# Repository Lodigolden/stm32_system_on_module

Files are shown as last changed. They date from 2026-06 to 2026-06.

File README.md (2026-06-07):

# STM32H7 System-on-Module
## Overview
This STM32H7 system-on-module is everything needed to get the MCU up and running. Simply place a footprint for the board-to-board connectors on your motherboard, and use whatever pins your project needs!

## Hardware
The system-on-module is a powerful compute source with everything you need for intensive computation. Peripherals include:
- STM32H743ZGT6 32Bit MCU
- AS4C8M16SA-7TCN 128MBit SDRAM
- AT25FF161A-SSHN-T 16MBit QSPI Flash
- CP2102N-A02-GQFN20R USB-to-UART Bridge

The system on module has a point-of-load regulator (TPSM861253RDXR) to ensure stable, efficient power delivery to on-board peripherals.

## Firmware
Included in this repository is a device tree file and other necessary files for building a zephyr image. The **fw/** README.md file gives instructions for building on a Linux system.

> TODO: Write instructions for Windows use.

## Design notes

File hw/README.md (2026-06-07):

# Overview
The **pinout/** directory includes an STMCubeIDE file used to deetermine pinouts for the on-board components. If the end user doesn't wish to use Zephyr and would rather use STMCubeIDE, they can feel free to start with that folder.

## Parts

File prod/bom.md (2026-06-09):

# Bill of Materials

| Part Number | QNTY |
|:---|----:|
| 10118192-0002LF | 1 |
| AS4C8M16SA-7TCN | 1 |
| AT25FF161A-SSHN-T | 1 |
| CL05B104KP5VPNC | 28 |
| CL10A475KO8NNNC | 3 |
| CL31A226MOCLNNC | 1 |
| CL31B106KAHNFNE | 1 |
| CP2102N-A02-GQFN20R | 1 |
| DF40C-50DP-0.4V(51) | 2 |
| ERJ-2RKF3300X | 1 |
| GRM155Z71A105KE01D | 2 |
| KC2016Z8.00000C15XXK | 1 |
| LO Q976-PS-25-0-20-R18 | 1 |
| MSS1P4-M3/89A | 2 |
| RC0402FR-071KL | 1 |
| RC0402FR-0722K1L | 1 |
| RC0402FR-0747K5L | 1 |
| RC0402FR-074K99L | 1 |
| RC0402JR-0733RL | 44 |
| RMCF0402FT10K0 | 2 |
| SMAJ7.0CA | 1 |
| STM32H743ZGT6 | 1 |
| TPD1E10B06DYAR | 2 |
| TPSM861253RDXR | 1 |

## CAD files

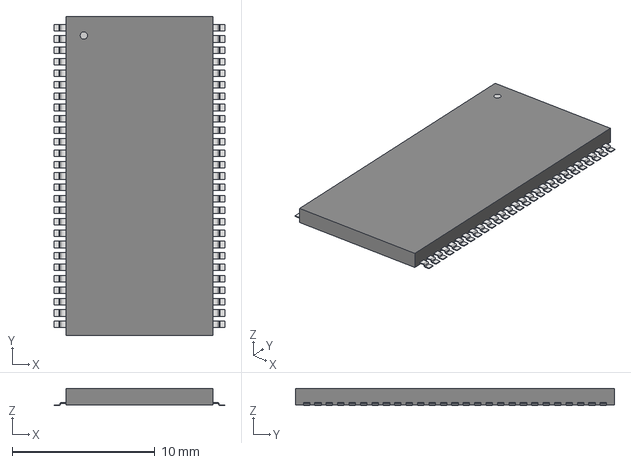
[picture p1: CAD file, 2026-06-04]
hw/components/as4c8m16sa_7tcn/TSOP-54_11P96X22P35_ALL.step
12.0 x 22.4 x 1.20 mm

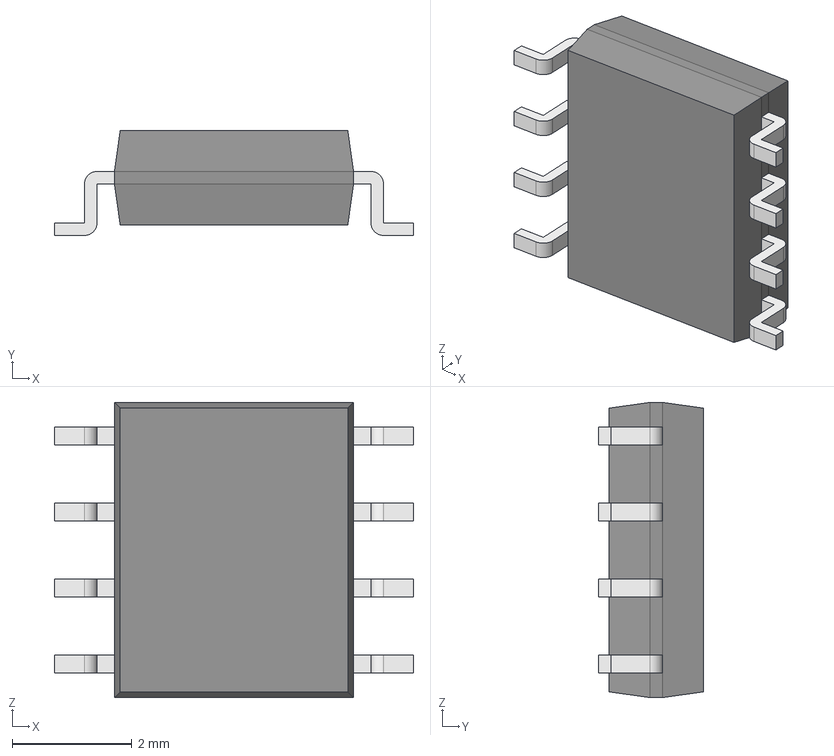
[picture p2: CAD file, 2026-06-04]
hw/components/at25ff161a/AT25FF161A-SSHN-T.step
5.99 x 1.75 x 4.92 mm
Body001 (Mirror #1) x 4
XY-plane x 12
X-axis x 12

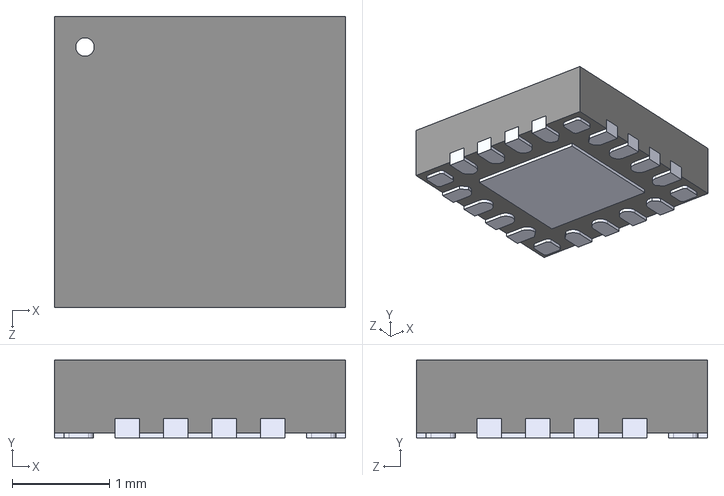
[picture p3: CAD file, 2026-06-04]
hw/components/cp2102n-a02-gqfn20r/CP2102N-A02-GQFN20R.step
3.00 x 0.8 x 3.00 mm

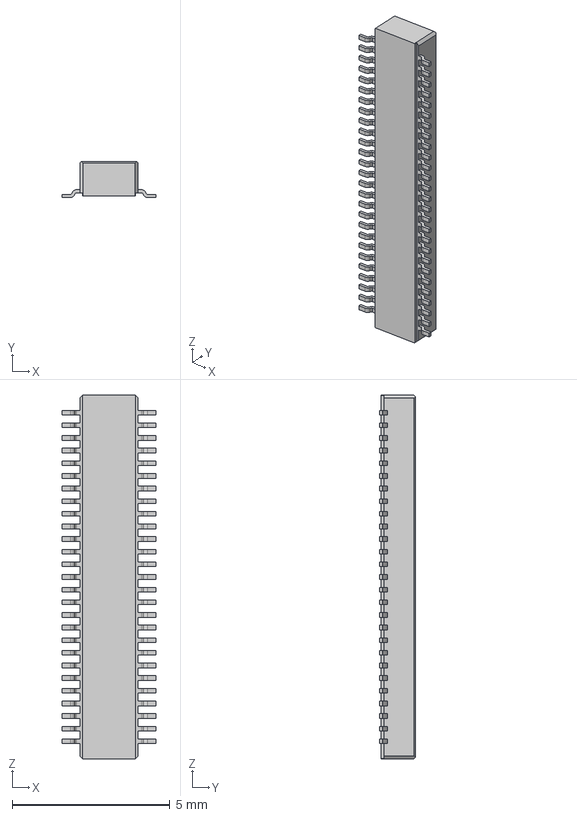
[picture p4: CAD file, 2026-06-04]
hw/components/dc40c_50dp_0.4v_51/DF40C-50DP-0.4V_51_.step
2.97 x 1.14 x 11.5 mm

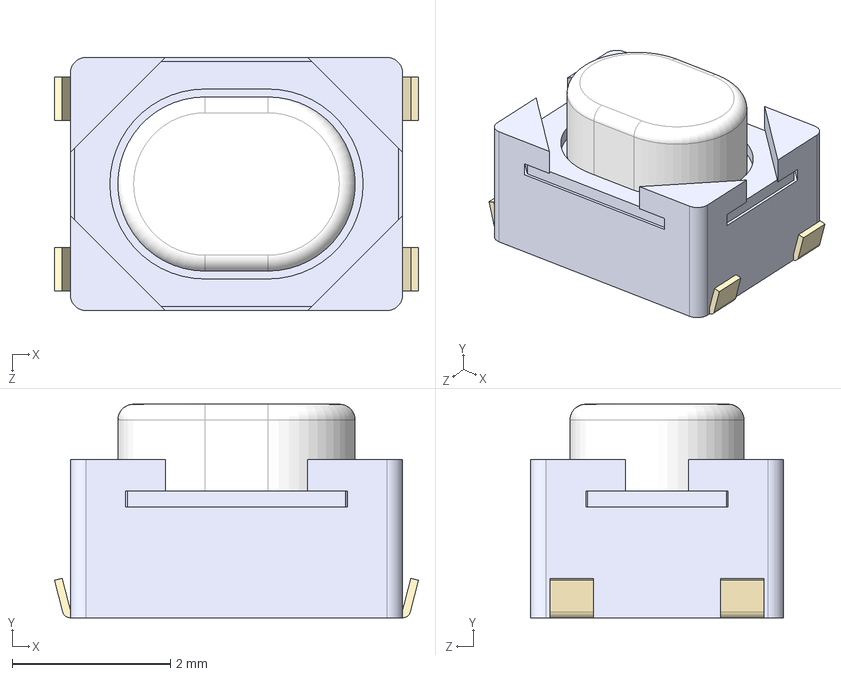
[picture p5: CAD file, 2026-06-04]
hw/components/PTS810SJK250SMTR_LFS/PTS810SJK250SMTRLFS--3DModel-STEP-56544.STEP
4.60 x 2.70 x 3.20 mm

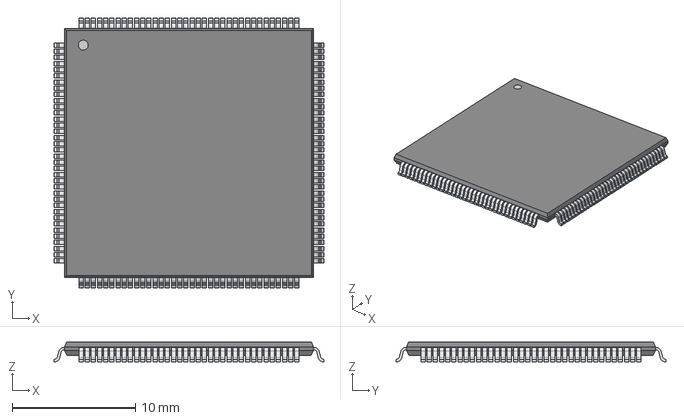
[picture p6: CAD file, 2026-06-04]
hw/components/stm32h743zgt6/LQFP144-20x20mm.step
21.9 x 21.9 x 1.60 mm

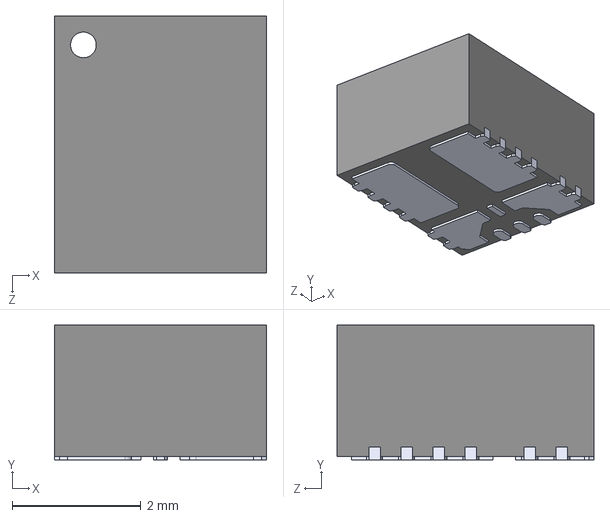
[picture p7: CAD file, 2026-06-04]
hw/components/tpsm861253/TPSM861253RDXR.step
3.30 x 2.10 x 4.00 mm

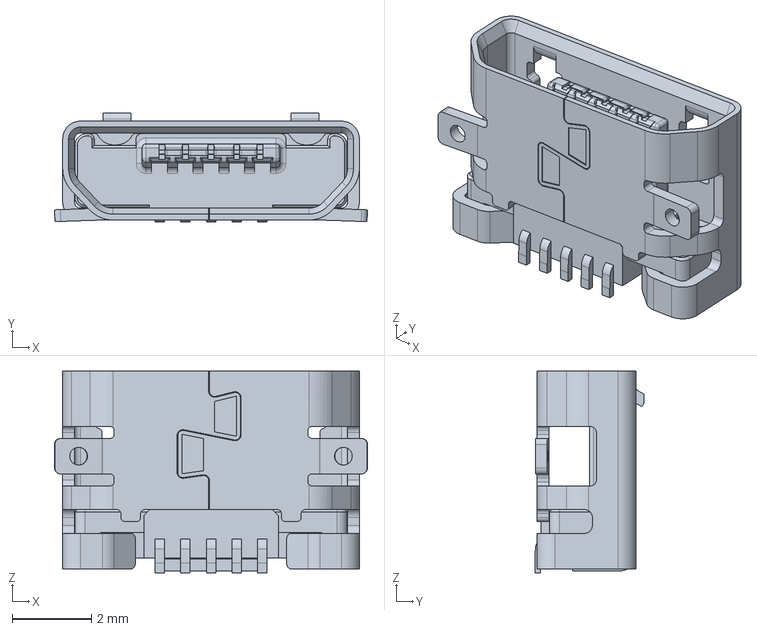
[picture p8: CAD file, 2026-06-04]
hw/components/10118192_0002LF/10118192-0002LF.step
7.91 x 2.77 x 5.10 mm

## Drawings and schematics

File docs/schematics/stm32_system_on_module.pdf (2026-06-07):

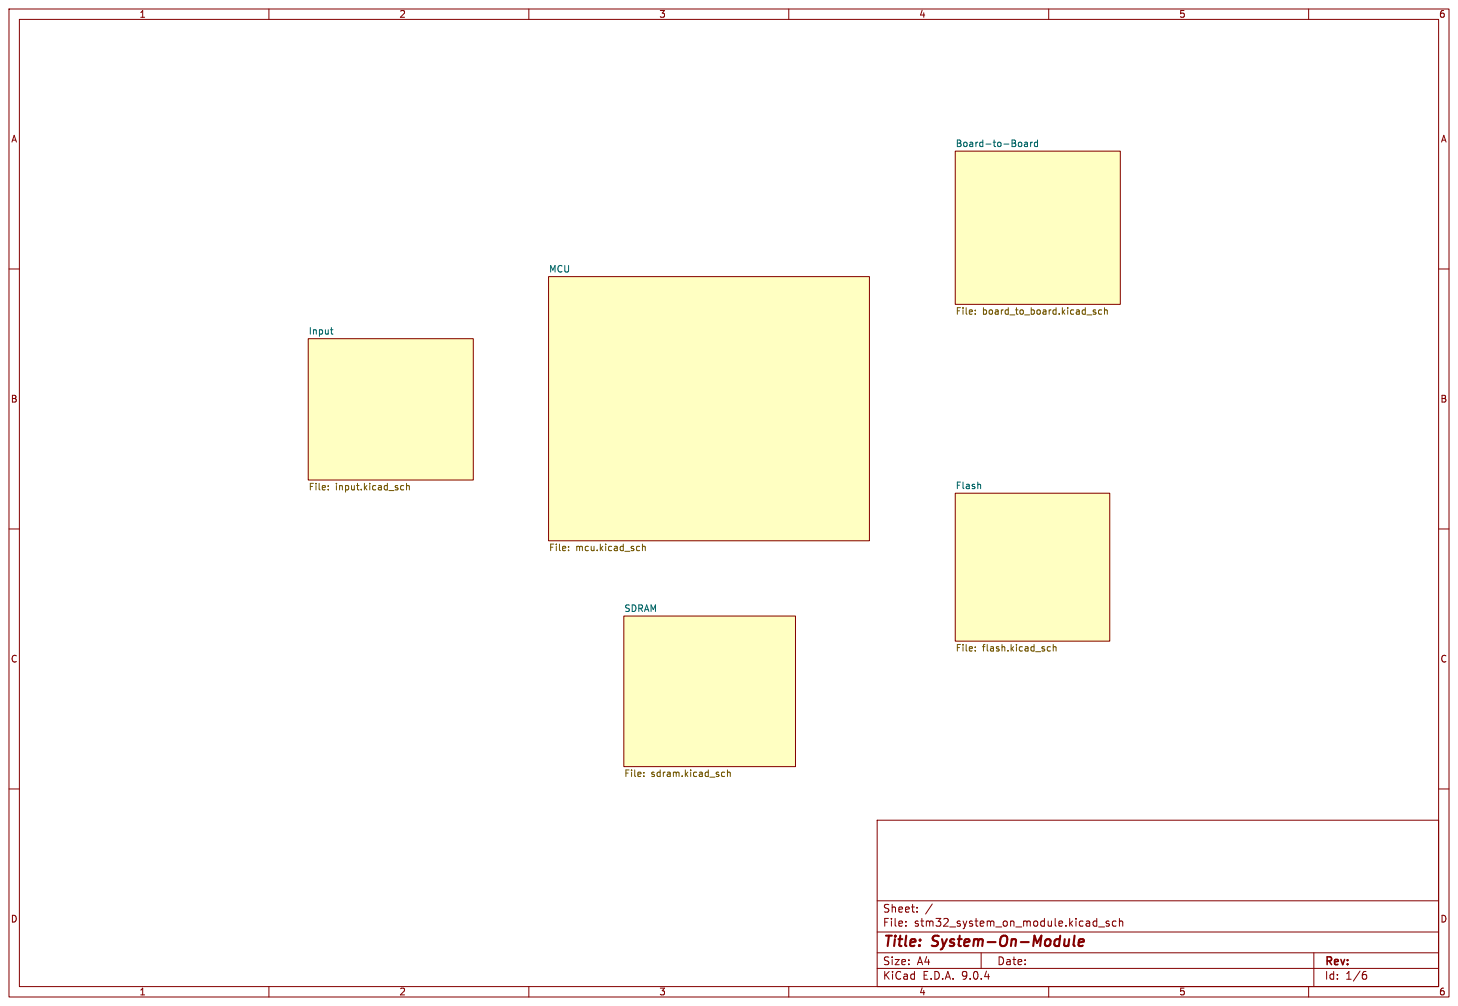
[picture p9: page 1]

Board-to-Board File: board_to_board.kicad_sch Flash File: flash.kicad_sch

File: stm32_system_on_module.kicad_sch Sheet: /
Id: 1/6 Title: System-On-Module

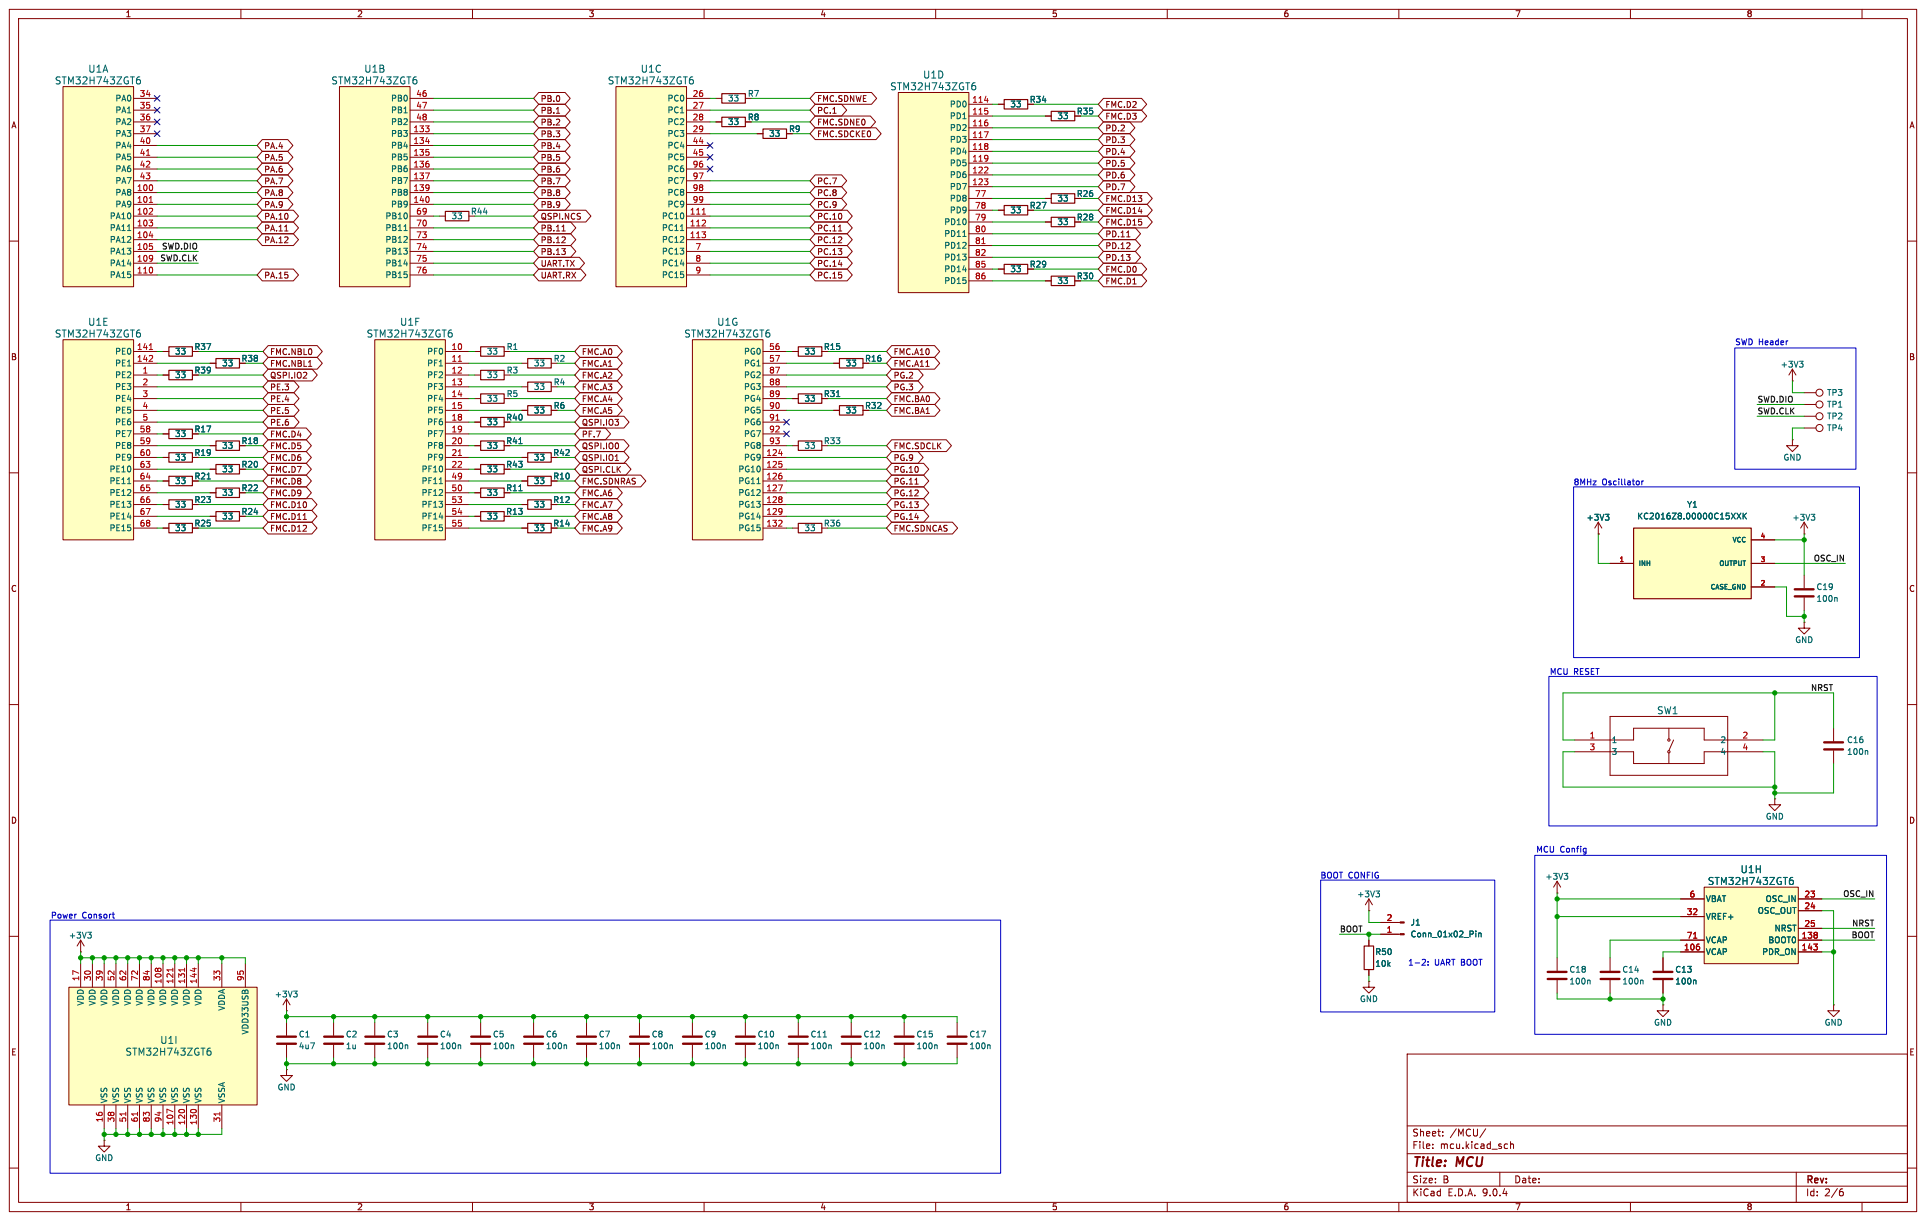
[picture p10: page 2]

FMC.D3 PD.5 PD.3 UART.RX

PD.4 FMC.D2 PC.12 PC.13 PC.15 PC.14 PC.9 PC.10 PC.7 PC.11 PC.8 PC.1 QSPI.CLK

PD.7 FMC.D15 FMC.D13 FMC.D14 FMC.SDNCAS

PG.13 PG.10 PG.12 PG.14 PG.9 FMC.SDCLK

File: mcu.kicad_sch Sheet: /MCU/ GND

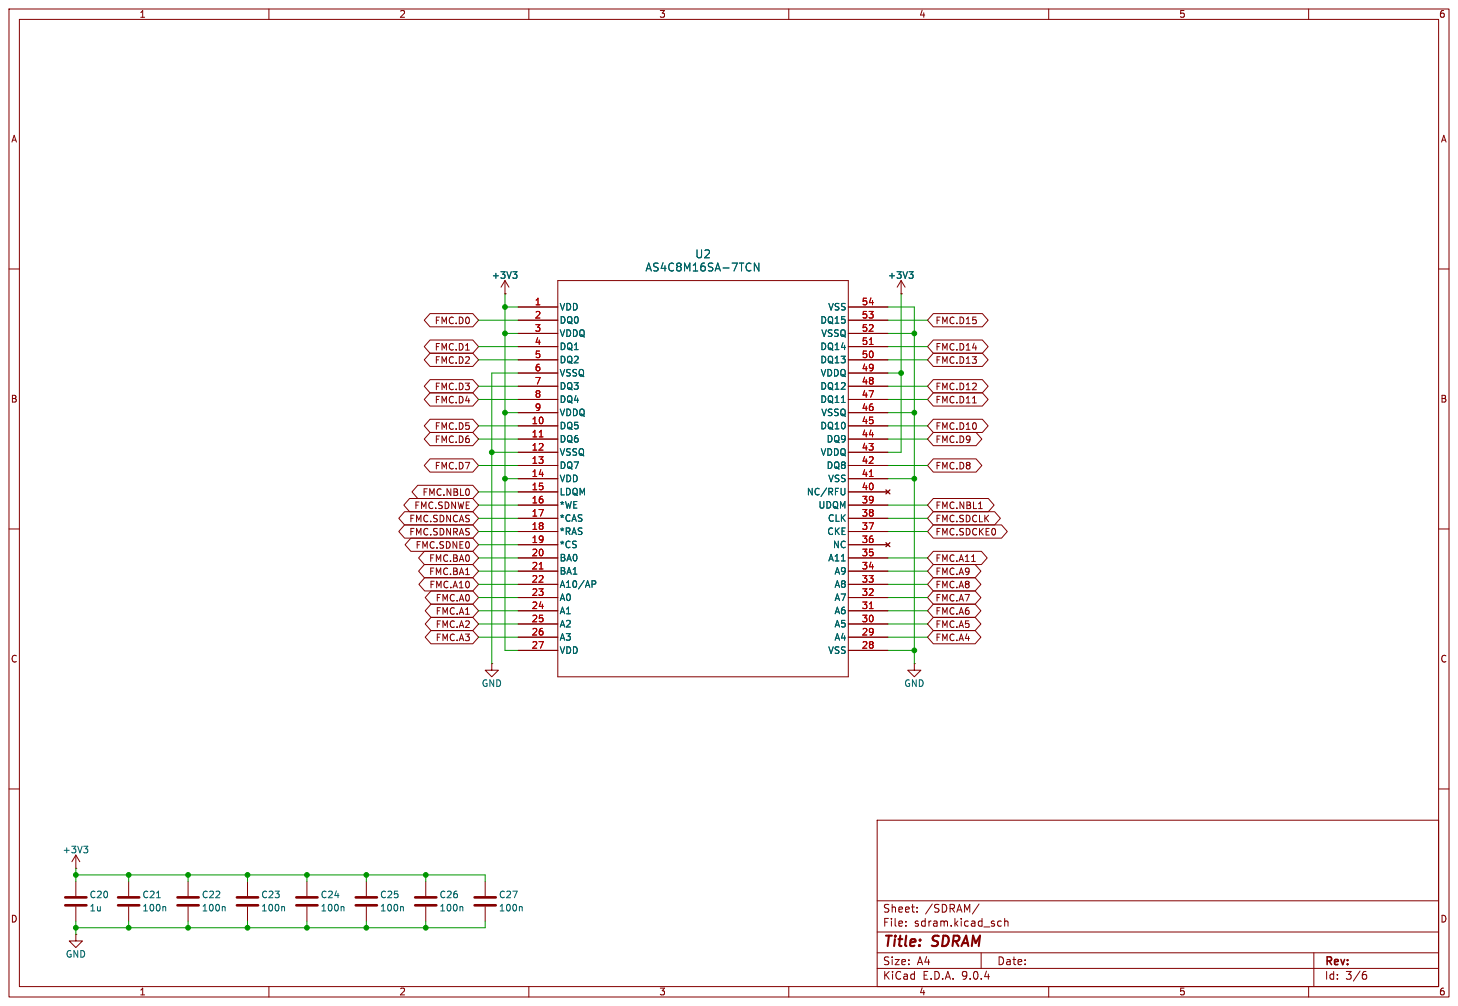
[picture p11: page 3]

File: sdram.kicad_sch Sheet: /SDRAM/ C23

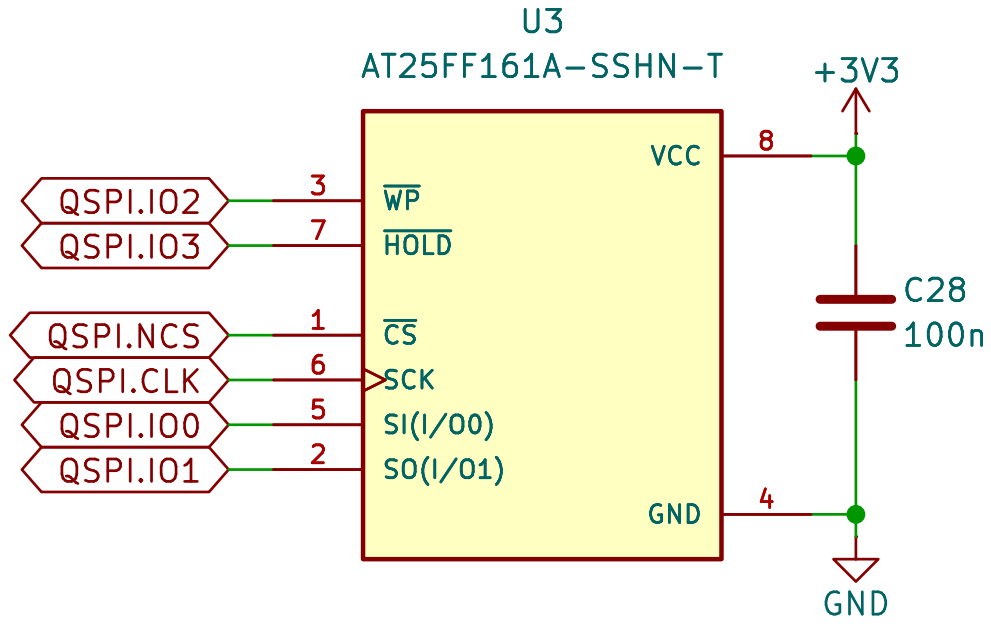
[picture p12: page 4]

100n GND QSPI.IO1 QSPI.CLK QSPI.IO0 QSPI.IO2 QSPI.IO3 QSPI.NCS

File: flash.kicad_sch Sheet: /Flash/
Id: 4/6 Title: QSPI Flash

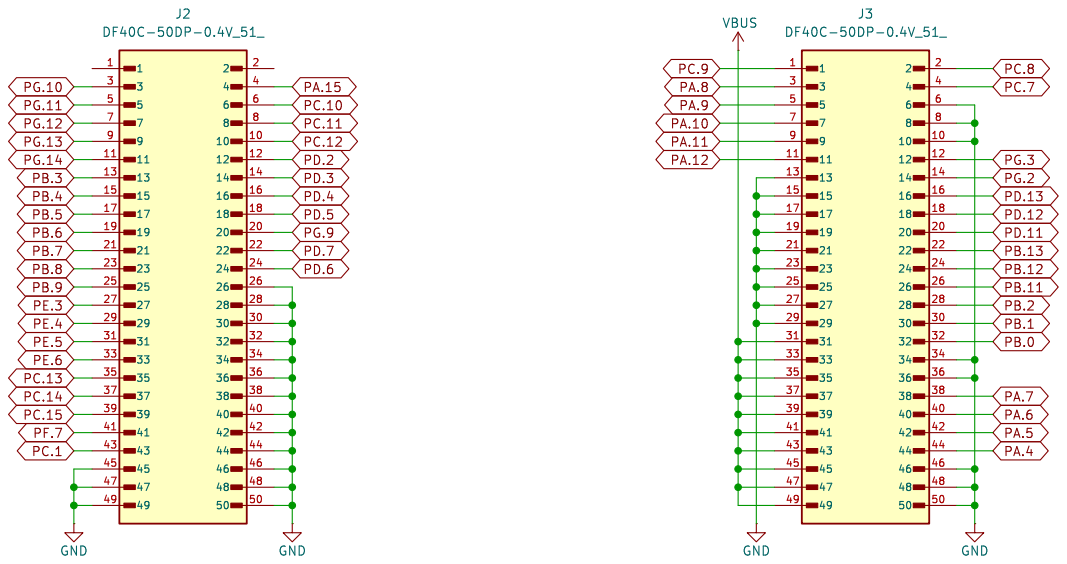
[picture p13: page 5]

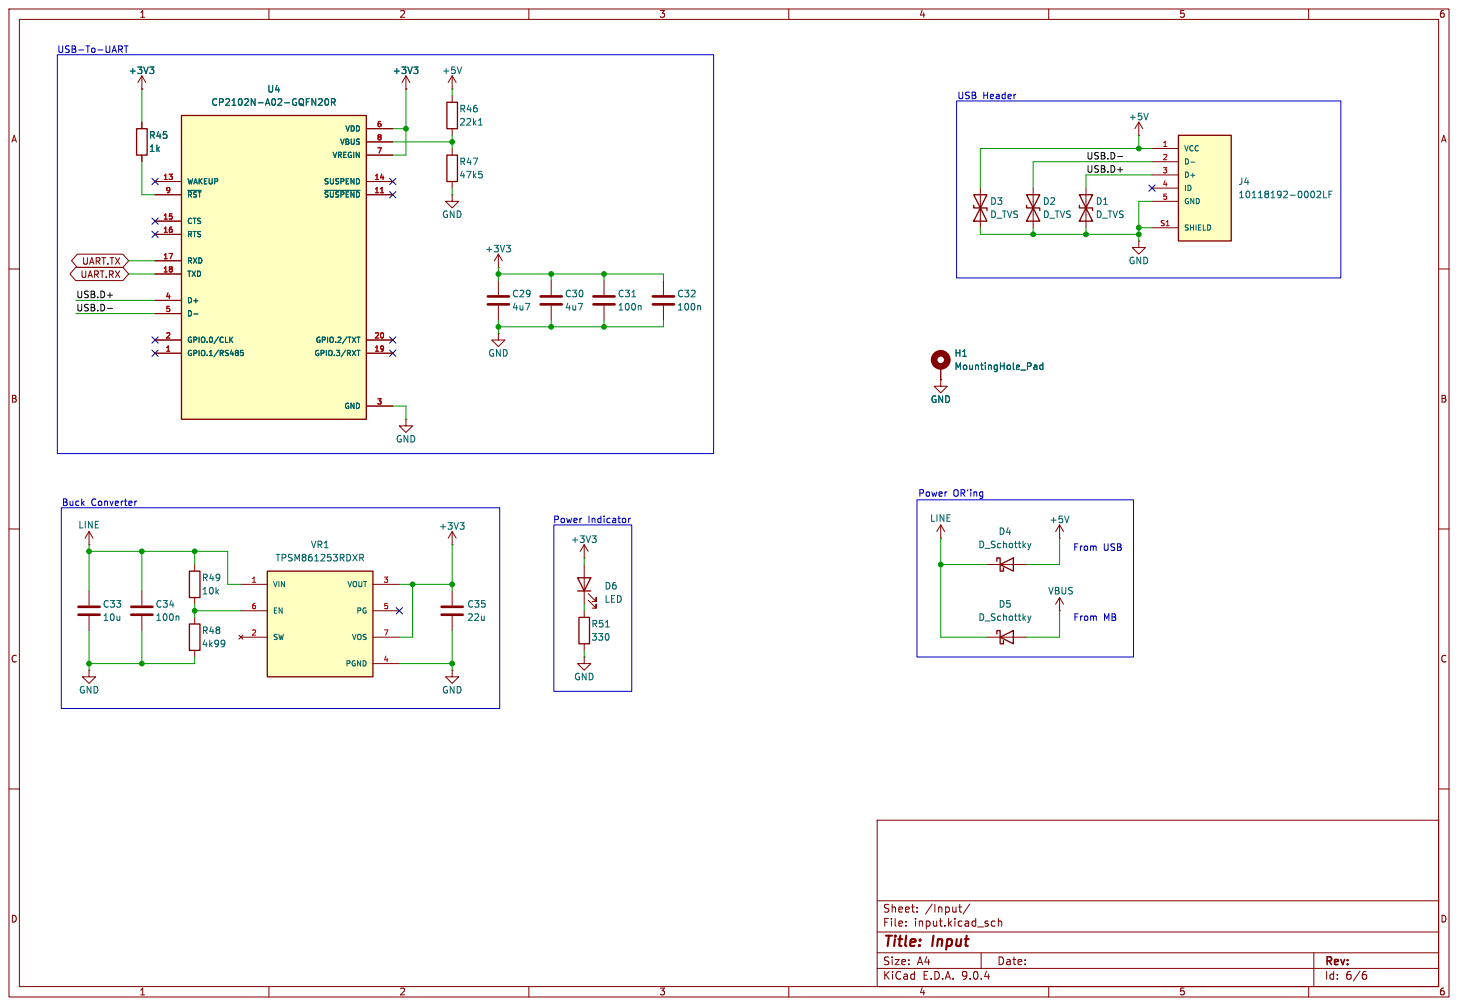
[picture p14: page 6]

LED GND
Id: 6/6 Title: Input File: input.kicad_sch Sheet: /Input/ C35

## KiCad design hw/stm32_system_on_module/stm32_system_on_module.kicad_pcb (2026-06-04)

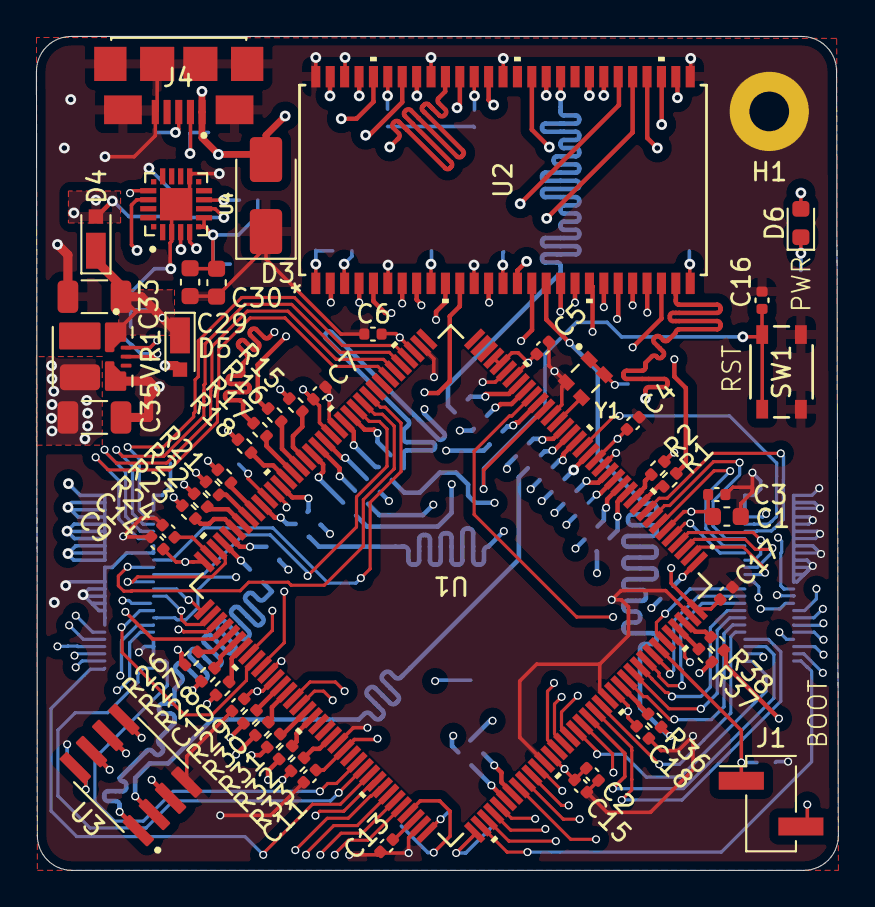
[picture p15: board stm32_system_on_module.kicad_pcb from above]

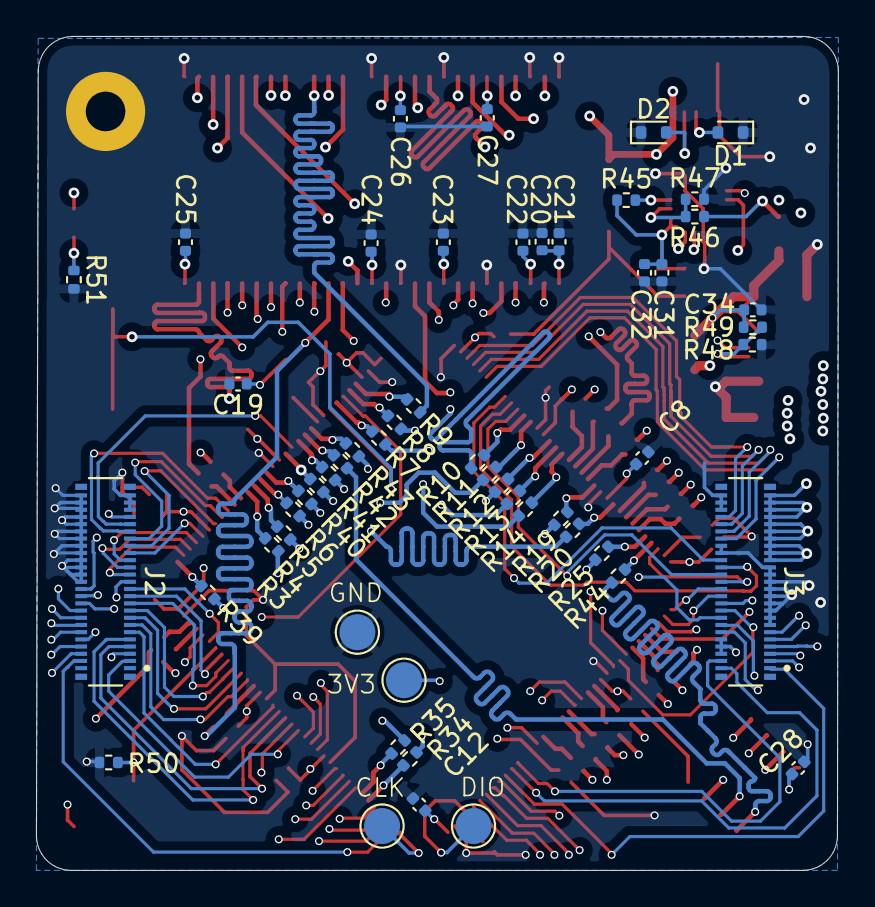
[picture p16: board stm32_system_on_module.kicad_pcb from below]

Board: 8 copper layers, 44.6 x 46.3 mm, 108 parts (53 on the bottom side), 163 nets.

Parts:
C1, C29, C30: 4u7; C_0603_1608Metric
C2, C20: 1u; C_0402_1005Metric
C3, C4, C5, C6, C7, C8, C9, C10, C11, C12, C13, C14, C15, C16, C17, C18, C19, C21, C22, C23, C24, C25, C26, C27, C28, C31, C32, C34: 100n; C_0402_1005Metric
C33: 10u; C_1206_3216Metric
C35: 22u; C_1206_3216Metric
D1, D2: D_TVS; D_SOD-523
D3: D_TVS; D_SMA
D4, D5: D_Schottky; D_MicroSMP_AK
D6: LED; LED_0603_1608Metric
H1: MountingHole_Pad; MountingHole_2.2mm_M2_Pad
J1: Conn_01x02_Pin; PinHeader_1x02_P2.54mm_Vertical_SMD_Pin1Left
J2, J3: DF40C-50DP-0.4V_51_; HIROSE_DF40C-50DP-0.4V_51_
J4: 10118192-0002LF; AMPHENOL_10118192-0002LF
R1, R2, R3, R4, R5, R6, R7, R8, R9, R10, R11, R12, R13, R14, R15, R16, R17, R18, R19, R20, R21, R22, R23, R24, R25, R26, R27, R28, R29, R30, R31, R32, R33, R34, R35, R36, R37, R38, R39, R40, R41, R42, R43, R44: 33; R_0402_1005Metric
R45: 1k; R_0402_1005Metric
R46: 22k1; R_0402_1005Metric
R47: 47k5; R_0402_1005Metric
R48: 4k99; R_0402_1005Metric
R49, R50: 10k; R_0402_1005Metric
R51: 330; R_0402_1005Metric
SW1: PTS810 SJK 250 SMTR LFS; PTS810_CNK
TP1, TP2, TP3, TP4: TestPoint; TestPoint_Pad_D2.0mm
U1: STM32H743ZGT6; stm32h743zgt6
U2: AS4C8M16SA-7TCN; TSOP-54_11P96X22P35_ALL
U3: AT25FF161A-SSHN-T; SOIC127P599X175-8N
U4: CP2102N-A02-GQFN20R; SILABS_CP2102N-A02-GQFN20R
VR1: TPSM861253RDXR; VREG_TPSM861253RDXR
Y1: KC2016Z8.00000C15XXK; OSC_KC2016Z8.00000C15XXK-4

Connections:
+3V3: C1.1, C2.1, C3.1, C4.1, C5.1, C6.1, C7.1, C8.1, C9.1, C10.1, C11.1, C12.1, C15.1, C17.1, C18.1, C19.1, C20.1, C21.1, C22.1, C23.1, C24.1, C25.1, C26.1, C27.1, C28.1, C29.1, C30.1, C31.1, C32.1, C35.1, D6.2 (A), J1.2, R45.1, TP3.1, U1.6 (VBAT), U1.17 (VDD), U1.30 (VDD), U1.32 (VREF+), U1.33 (VDDA), U1.39 (VDD), U1.52 (VDD), U1.62 (VDD), U1.72 (VDD), U1.84 (VDD), U1.95 (VDD33USB), U1.108 (VDD), U1.121 (VDD), U1.131 (VDD), U1.144 (VDD), U2.1 (VDD), U2.3 (VDDQ), U2.9 (VDDQ), U2.14 (VDD), U2.27 (VDD), U2.43 (VDDQ), U2.49 (VDDQ), U3.8 (VCC), U4.6 (VDD), U4.7 (VREGIN), VR1.3 (VOUT), VR1.7 (VOS), Y1.1 (INH), Y1.4 (VCC)
+5V: D3.2 (A2), D4.2 (A), J4.1 (VCC), R46.1
/Input/USB.D+: D1.2 (A2), J4.3 (D+), U4.4 (D+)
/Input/USB.D-: D2.2 (A2), J4.2 (D-), U4.5 (D-)
/MCU/BOOT: J1.1, R50.1, U1.138 (BOOT0)
/MCU/NRST: C16.1, SW1.1, SW1.2, U1.25 (NRST)
/MCU/OSC_IN: U1.23 (OSC_IN), Y1.3 (OUTPUT)
/MCU/SWD.CLK: TP2.1, U1.109 (PA14)
/MCU/SWD.DIO: TP1.1, U1.105 (PA13)
FMC.A0: R1.2, U2.23 (A0)
FMC.A1: R2.2, U2.24 (A1)
FMC.A2: R3.2, U2.25 (A2)
FMC.A3: R4.2, U2.26 (A3)
FMC.A4: R5.2, U2.29 (A4)
FMC.A5: R6.2, U2.30 (A5)
FMC.A6: R11.2, U2.31 (A6)
FMC.A7: R12.2, U2.32 (A7)
FMC.A8: R13.2, U2.33 (A8)
FMC.A9: R14.2, U2.34 (A9)
FMC.A10: R15.2, U2.22 (A10/AP)
FMC.A11: R16.2, U2.35 (A11)
FMC.BA0: R31.2, U2.20 (BA0)
FMC.BA1: R32.2, U2.21 (BA1)
FMC.D0: R29.2, U2.2 (DQ0)
FMC.D1: R30.2, U2.4 (DQ1)
FMC.D2: R34.2, U2.5 (DQ2)
FMC.D3: R35.2, U2.7 (DQ3)
FMC.D4: R17.2, U2.8 (DQ4)
FMC.D5: R18.2, U2.10 (DQ5)
FMC.D6: R19.2, U2.11 (DQ6)
FMC.D7: R20.2, U2.13 (DQ7)
FMC.D8: R21.2, U2.42 (DQ8)
FMC.D9: R22.2, U2.44 (DQ9)
FMC.D10: R23.2, U2.45 (DQ10)
FMC.D11: R24.2, U2.47 (DQ11)
FMC.D12: R25.2, U2.48 (DQ12)
FMC.D13: R26.2, U2.50 (DQ13)
FMC.D14: R27.2, U2.51 (DQ14)
FMC.D15: R28.2, U2.53 (DQ15)
FMC.NBL0: R37.2, U2.15 (LDQM)
FMC.NBL1: R38.2, U2.39 (UDQM)
FMC.SDCKE0: R9.2, U2.37 (CKE)
FMC.SDCLK: R33.2, U2.38 (CLK)
FMC.SDNCAS: R36.2, U2.17 (*CAS)
FMC.SDNE0: R8.2, U2.19 (*CS)
FMC.SDNRAS: R10.2, U2.18 (*RAS)
FMC.SDNWE: R7.2, U2.16 (*WE)
GND: C1.2, C2.2, C3.2, C4.2, C5.2, C6.2, C7.2, C8.2, C9.2, C10.2, C11.2, C12.2, C13.2, C14.2, C15.2, C16.2, C17.2, C18.2, C19.2, C20.2, C21.2, C22.2, C23.2, C24.2, C25.2, C26.2, C27.2, C28.2, C29.2, C30.2, C31.2, C32.2, C33.2, C34.2, C35.2, D1.1 (A1), D2.1 (A1), D3.1 (A1), H1.1, J2.26, J2.28, J2.30, J2.32, J2.34, J2.36, J2.38, J2.40, J2.42, J2.44, J2.45, J2.46, J2.47, J2.48, J2.49, J2.50, J3.6, J3.8, J3.10, J3.13, J3.15, J3.17, J3.19, J3.21, J3.23, J3.25, J3.27, J3.29, J3.34, J3.36, J3.46, J3.48, J3.50, J4.5 (GND), J4.S1 (SHIELD), J4.S2 (SHIELD), J4.S3 (SHIELD), J4.S4 (SHIELD), J4.S5 (SHIELD), J4.S6 (SHIELD), R47.2, R48.2, R50.2, R51.2, SW1.3, SW1.4, TP4.1, U1.16 (VSS), U1.24 (OSC_OUT), U1.31 (VSSA), U1.38 (VSS), U1.51 (VSS), U1.61 (VSS), U1.83 (VSS), U1.94 (VSS), U1.107 (VSS), U1.120 (VSS), U1.130 (VSS), U1.143 (PDR_ON), U2.6 (VSSQ), U2.12 (VSSQ), U2.28 (VSS), U2.41 (VSS), U2.46 (VSSQ), U2.52 (VSSQ), U2.54 (VSS), U3.4 (GND), U4.3 (GND), U4.12 (GND), U4.21 (GND), VR1.4 (PGND), Y1.2 (CASE_GND)
LINE: C33.1, C34.1, D4.1 (K), D5.1 (K), R49.1, VR1.1 (VIN)
unnamed: C13.1, U1.106 (VCAP)
unnamed: C14.1, U1.71 (VCAP)
unnamed: D6.1 (K), R51.1
unnamed: R44.1, U1.69 (PB10)
unnamed: R7.1, U1.26 (PC0)
unnamed: R8.1, U1.28 (PC2)
unnamed: R9.1, U1.29 (PC3)
unnamed: R34.1, U1.114 (PD0)
unnamed: R35.1, U1.115 (PD1)
unnamed: R26.1, U1.77 (PD8)
unnamed: R27.1, U1.78 (PD9)
unnamed: R28.1, U1.79 (PD10)
unnamed: R29.1, U1.85 (PD14)
unnamed: R30.1, U1.86 (PD15)
unnamed: R37.1, U1.141 (PE0)
unnamed: R38.1, U1.142 (PE1)
unnamed: R39.1, U1.1 (PE2)
unnamed: R17.1, U1.58 (PE7)
unnamed: R18.1, U1.59 (PE8)
unnamed: R19.1, U1.60 (PE9)
unnamed: R20.1, U1.63 (PE10)
unnamed: R21.1, U1.64 (PE11)
unnamed: R22.1, U1.65 (PE12)
unnamed: R23.1, U1.66 (PE13)
unnamed: R24.1, U1.67 (PE14)
unnamed: R25.1, U1.68 (PE15)
unnamed: R1.1, U1.10 (PF0)
unnamed: R2.1, U1.11 (PF1)
unnamed: R3.1, U1.12 (PF2)
unnamed: R4.1, U1.13 (PF3)
unnamed: R5.1, U1.14 (PF4)
unnamed: R6.1, U1.15 (PF5)
unnamed: R40.1, U1.18 (PF6)
unnamed: R41.1, U1.20 (PF8)
unnamed: R42.1, U1.21 (PF9)
unnamed: R43.1, U1.22 (PF10)
unnamed: R10.1, U1.49 (PF11)
unnamed: R11.1, U1.50 (PF12)
unnamed: R12.1, U1.53 (PF13)
unnamed: R13.1, U1.54 (PF14)
unnamed: R14.1, U1.55 (PF15)
unnamed: R15.1, U1.56 (PG0)
unnamed: R16.1, U1.57 (PG1)
unnamed: R31.1, U1.89 (PG4)
unnamed: R32.1, U1.90 (PG5)
unnamed: R33.1, U1.93 (PG8)
unnamed: R36.1, U1.132 (PG15)
unnamed: R46.2, R47.1, U4.8 (VBUS)
unnamed: R45.2, U4.9 (~RST)
unnamed: R48.1, R49.2, VR1.6 (EN)
PA.4: J3.44, U1.40 (PA4)
PA.5: J3.42, U1.41 (PA5)
PA.6: J3.40, U1.42 (PA6)
PA.7: J3.38, U1.43 (PA7)
PA.8: J3.3, U1.100 (PA8)
PA.9: J3.5, U1.101 (PA9)
PA.10: J3.7, U1.102 (PA10)
PA.11: J3.9, U1.103 (PA11)
PA.12: J3.11, U1.104 (PA12)
PA.15: J2.4, U1.110 (PA15)
PB.0: J3.32, U1.46 (PB0)
PB.1: J3.30, U1.47 (PB1)
PB.2: J3.28, U1.48 (PB2)
PB.3: J2.13, U1.133 (PB3)
PB.4: J2.15, U1.134 (PB4)
PB.5: J2.17, U1.135 (PB5)
PB.6: J2.19, U1.136 (PB6)
PB.7: J2.21, U1.137 (PB7)
PB.8: J2.23, U1.139 (PB8)
PB.9: J2.25, U1.140 (PB9)
PB.11: J3.26, U1.70 (PB11)
PB.12: J3.24, U1.73 (PB12)
PB.13: J3.22, U1.74 (PB13)
PC.1: J2.43, U1.27 (PC1)
PC.7: J3.4, U1.97 (PC7)
PC.8: J3.2, U1.98 (PC8)
PC.9: J3.1, U1.99 (PC9)
PC.10: J2.6, U1.111 (PC10)
PC.11: J2.8, U1.112 (PC11)
PC.12: J2.10, U1.113 (PC12)
PC.13: J2.35, U1.7 (PC13)
PC.14: J2.37, U1.8 (PC14)
PC.15: J2.39, U1.9 (PC15)
PD.2: J2.12, U1.116 (PD2)
PD.3: J2.14, U1.117 (PD3)
PD.4: J2.16, U1.118 (PD4)
PD.5: J2.18, U1.119 (PD5)
PD.6: J2.24, U1.122 (PD6)
PD.7: J2.22, U1.123 (PD7)
PD.11: J3.20, U1.80 (PD11)
PD.12: J3.18, U1.81 (PD12)
PD.13: J3.16, U1.82 (PD13)
PE.3: J2.27, U1.2 (PE3)
PE.4: J2.29, U1.3 (PE4)
PE.5: J2.31, U1.4 (PE5)
PE.6: J2.33, U1.5 (PE6)
PF.7: J2.41, U1.19 (PF7)
PG.2: J3.14, U1.87 (PG2)
PG.3: J3.12, U1.88 (PG3)
PG.9: J2.20, U1.124 (PG9)
PG.10: J2.3, U1.125 (PG10)
PG.11: J2.5, U1.126 (PG11)
PG.12: J2.7, U1.127 (PG12)
PG.13: J2.9, U1.128 (PG13)
PG.14: J2.11, U1.129 (PG14)
QSPI.CLK: R43.2, U3.6 (SCK)
QSPI.IO0: R41.2, U3.5 (SI(I/O0))
QSPI.IO1: R42.2, U3.2 (SO(I/O1))
QSPI.IO2: R39.2, U3.3 (~WP)
QSPI.IO3: R40.2, U3.7 (~HOLD)
QSPI.NCS: R44.2, U3.1 (~CS)
UART.RX: U1.76 (PB15), U4.18 (TXD)
UART.TX: U1.75 (PB14), U4.17 (RXD)
VBUS: D5.2 (A), J3.31, J3.33, J3.35, J3.37, J3.39, J3.41, J3.43, J3.45, J3.47, J3.49

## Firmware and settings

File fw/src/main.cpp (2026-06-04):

////////////////////////////////////////////////////////////////////////////////////////////////////
// Include(s)
////////////////////////////////////////////////////////////////////////////////////////////////////
#include <zephyr/kernel.h>

////////////////////////////////////////////////////////////////////////////////////////////////////
int main()
{
    while (true)
    {
        k_sleep(K_MSEC(100));
    }

    return 0;
}

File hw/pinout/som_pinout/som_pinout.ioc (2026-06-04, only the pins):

Mcu.UserName=STM32H743ZGTx
PB10.Signal=QUADSPI_BK1_NCS
PB14.Signal=USART1_TX
PB15.Signal=USART1_RX
PC0.Signal=FMC_SDNWE
PC2_C.Signal=FMC_SDNE0
PC3_C.Signal=FMC_SDCKE0
PD0.Signal=FMC_D2_DA2
PD1.Signal=FMC_D3_DA3
PD10.Signal=FMC_D15_DA15
PD14.Signal=FMC_D0_DA0
PD15.Signal=FMC_D1_DA1
PD8.Signal=FMC_D13_DA13
PD9.Signal=FMC_D14_DA14
PE0.Signal=FMC_NBL0
PE1.Signal=FMC_NBL1
PE10.Signal=FMC_D7_DA7
PE11.Signal=FMC_D8_DA8
PE12.Signal=FMC_D9_DA9
PE13.Signal=FMC_D10_DA10
PE14.Signal=FMC_D11_DA11
PE15.Signal=FMC_D12_DA12
PE2.Signal=QUADSPI_BK1_IO2
PE7.Signal=FMC_D4_DA4
PE8.Signal=FMC_D5_DA5
PE9.Signal=FMC_D6_DA6
PF0.Signal=FMC_A0
PF1.Signal=FMC_A1
PF10.Signal=QUADSPI_CLK
PF11.Signal=FMC_SDNRAS
PF12.Signal=FMC_A6
PF13.Signal=FMC_A7
PF14.Signal=FMC_A8
PF15.Signal=FMC_A9
PF2.Signal=FMC_A2
PF3.Signal=FMC_A3
PF4.Signal=FMC_A4
PF5.Signal=FMC_A5
PF6.Signal=QUADSPI_BK1_IO3
PF8.Signal=QUADSPI_BK1_IO0
PF9.Signal=QUADSPI_BK1_IO1
PG0.Signal=FMC_A10
PG1.Signal=FMC_A11
PG15.Signal=FMC_SDNCAS
PG4.Signal=FMC_A14_BA0
PG5.Signal=FMC_A15_BA1
PG8.Signal=FMC_SDCLK

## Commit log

2026-04-02 schematic and layout progress
    [10118192-0002LF.step, AT25FF161A-SSHN-T.step, CP2102N-A02-GQFN20R.step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]
2026-05-26 HW finished
    [PTS810SJK250SMTRLFS--3DModel-STEP-56544.STEP, board_to_board.kicad_sch, input.kicad_sch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]
2026-06-04 Added flash driver
2026-06-07 Added HW schematic
2026-06-09 Added BoM
